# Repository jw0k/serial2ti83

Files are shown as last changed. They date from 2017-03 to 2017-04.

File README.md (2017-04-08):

# serial2ti83
A program for Arduino Uno that makes it possible to connect a TI-83 calculator to a computer

## Introduction
This program turns an Arduino Uno board into an adapter between a TI-83 graphing calculator and a computer. In order to use it upload `serial2ti83.ino` to an Arduino board using the standard Arduino IDE and connect the 2.5mm jack port on the bottom of TI-83 to Arduino according to the following table:

| Jack port | Arduino | 
|:---:|:---:|
| sleeve | GND pin |
| tip | pin 2 |
| ring | pin 3 | 
   
You can now run some linking program, e.g. **TiLP** and start exchanging data (upload programs, take screenshots, dump ROM, manage variables, etc.). In case of TiLP make sure to go to File->Change Device first and choose **GrayLink** cable and TI-83 calc.

_Optional_: before uploading `serial2ti83.ino` it is recommended to increase the size of hardware serial buffers to make the connection more reliable. Open `HardwareSerial.h` from you Arduino installation folder (usually `C:\Program Files (x86)\Arduino\hardware\arduino\avr\cores\arduino`) and change these 2 lines:

    #define SERIAL_TX_BUFFER_SIZE 64
    #define SERIAL_RX_BUFFER_SIZE 64

to:

    #define SERIAL_TX_BUFFER_SIZE 256
    #define SERIAL_RX_BUFFER_SIZE 256
    
## Schematic

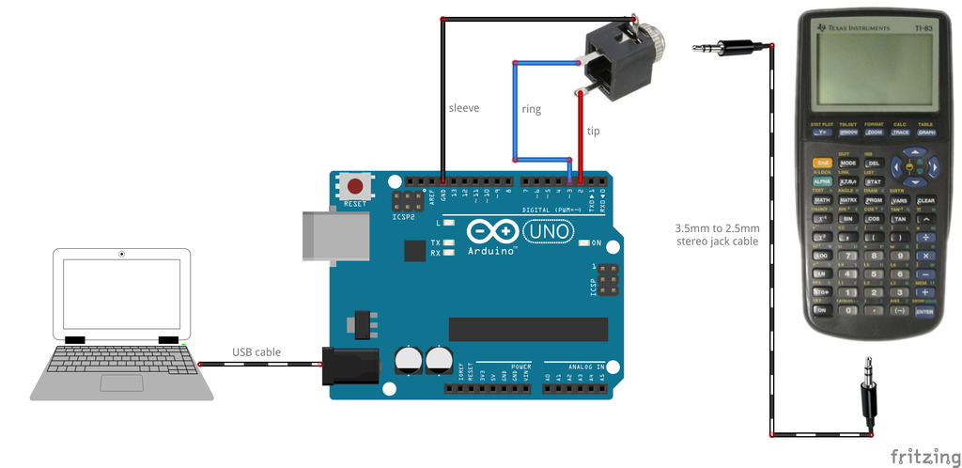
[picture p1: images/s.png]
schematic


## Putting it in a box
Here is an example of how you can put an Arduino board inside a box and attach a 3.5mm jack socket to the box to make a device that is convenient to use.

### List of required items
* Arduino Uno board (or clone)
* plastic project box (search for "ABS Plastic Electronic Enclosure Project Box Black 103x64x40mm" on **Banggood**, it's about $3.5)

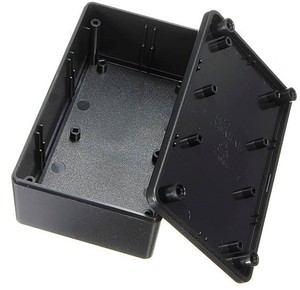
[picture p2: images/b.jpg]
box


* 3.5mm panel mounted stereo jack socket (eBay, $0.99)

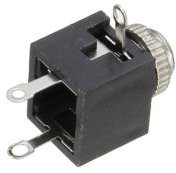
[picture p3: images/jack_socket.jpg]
jack socket


* nylon M3x10mm standoffs (eBay, $1.69 for 25 pieces)
* nylon M3x6mm philips screws (eBay, $1.79 for 25 pieces)
* 3.5mm to 2.5mm stereo jack cable (eBay, $0.99)

*Note: not every 2.5mm jack plug fits TI-83 smoothly. You may need to file away bits of plug's plastic housing so it goes all the way into the socket*

* some jumper cables
* basic tools (soldering iron, philips screwdriver, dremel tool, drill, files, etc.)

### Assembling the device

The first step is to attach standoffs to the Arduino board:

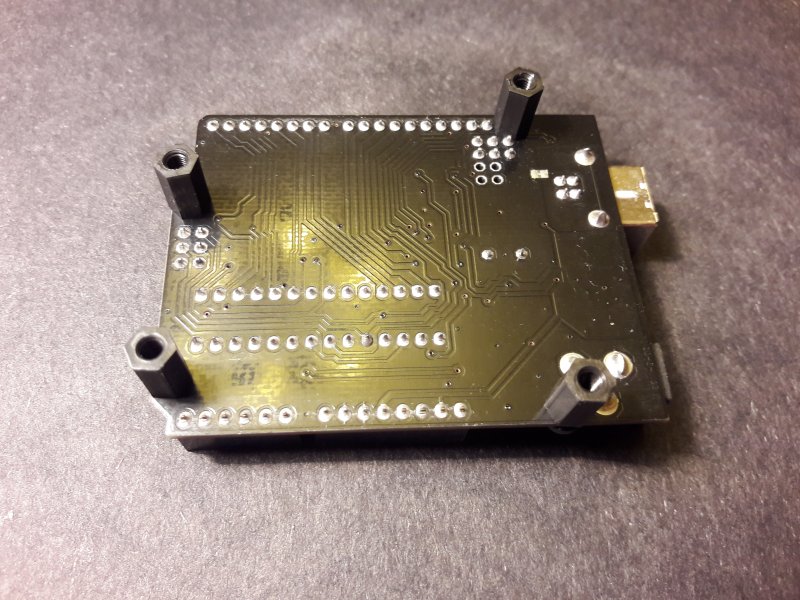
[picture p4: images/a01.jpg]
a01


Sometimes you will need to file edges of the DC socket and connector headers to make space for screws.

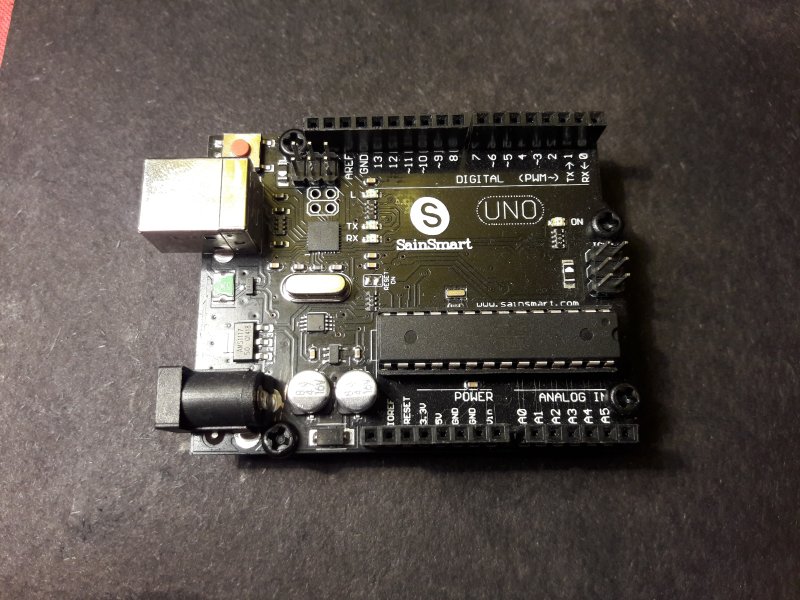
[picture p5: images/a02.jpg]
a02


Drill 4 holes in the bottom part of the box. The holes should match Arduino's layout:

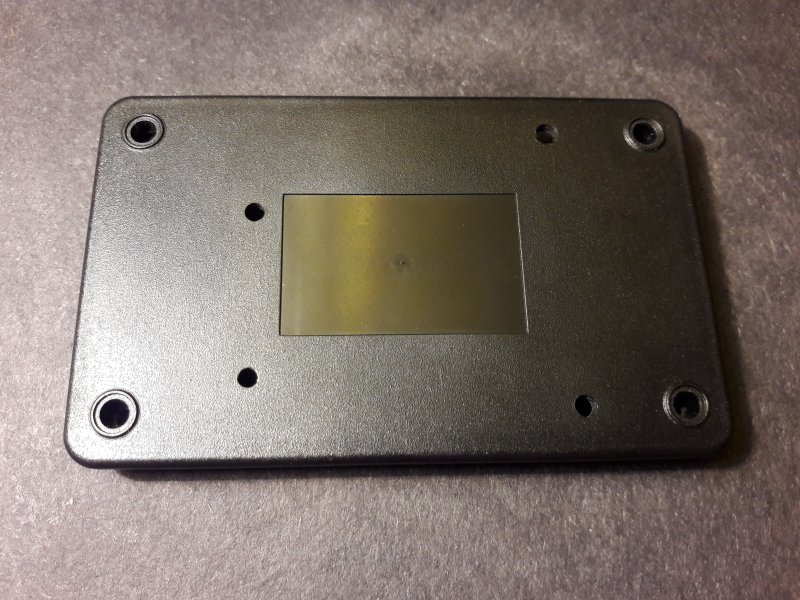
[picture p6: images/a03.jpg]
a03


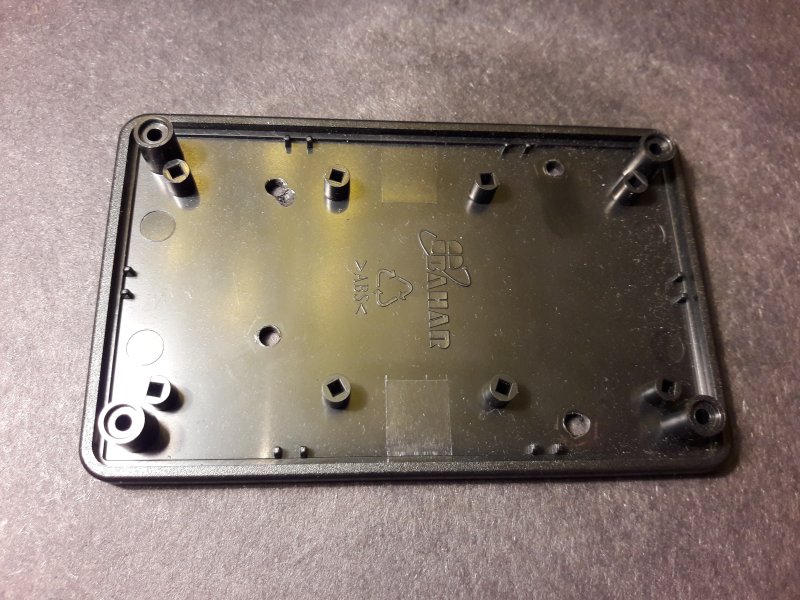
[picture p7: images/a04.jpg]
a04


Screw the Arduino board to it:

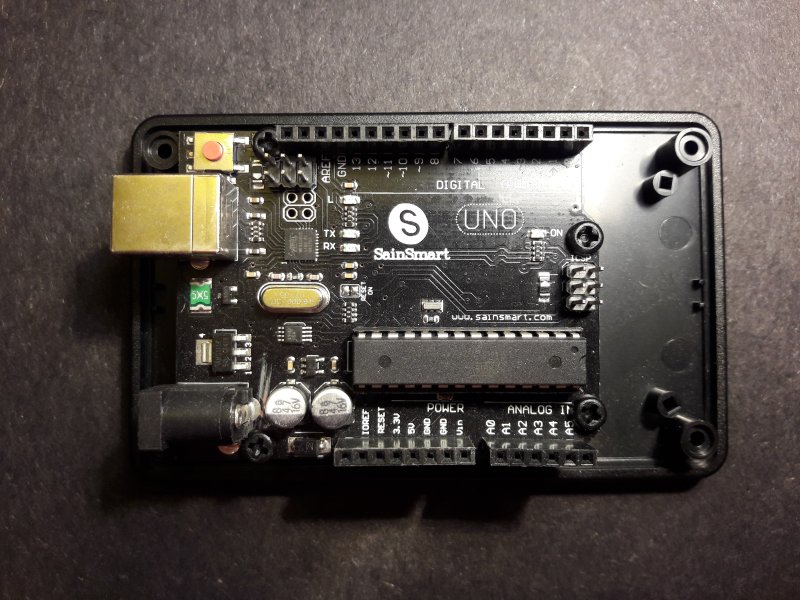
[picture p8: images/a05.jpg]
a05


Make a rectangular opening for the USB plug in the top part of the box. You may use a drill and finish with a file. The opening should be correctly positioned so that it matches with the USB socket.

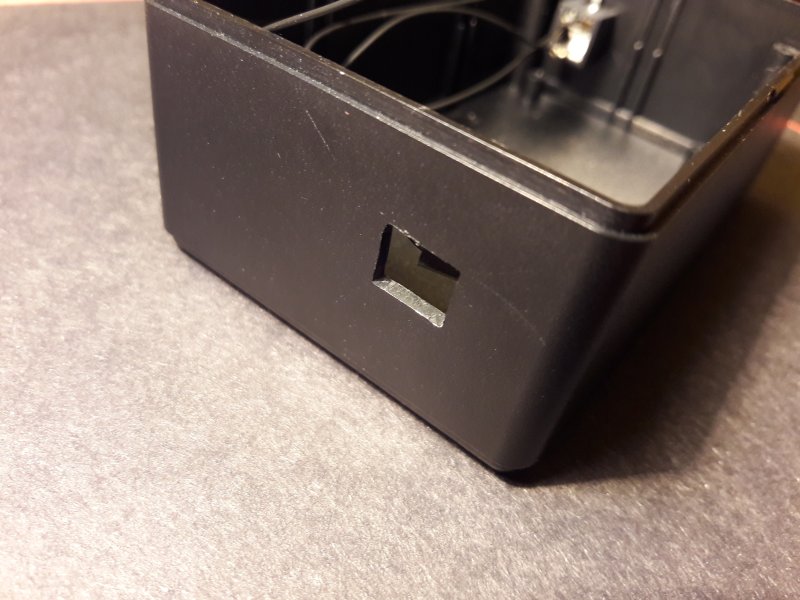
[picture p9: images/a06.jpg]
a06


Drill a hole on the other side of the top part of the box and attach the 3.5mm jack socket. Solder 3 jumper cables to it.

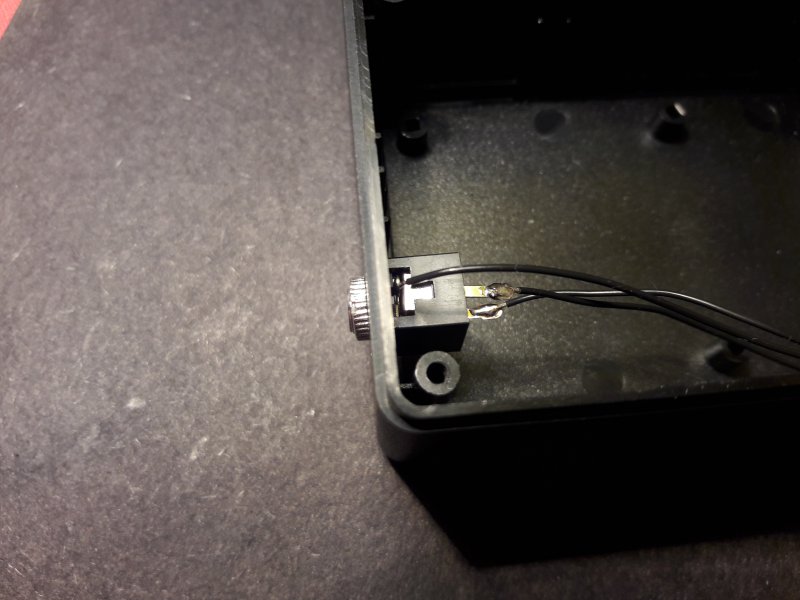
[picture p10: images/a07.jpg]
a07


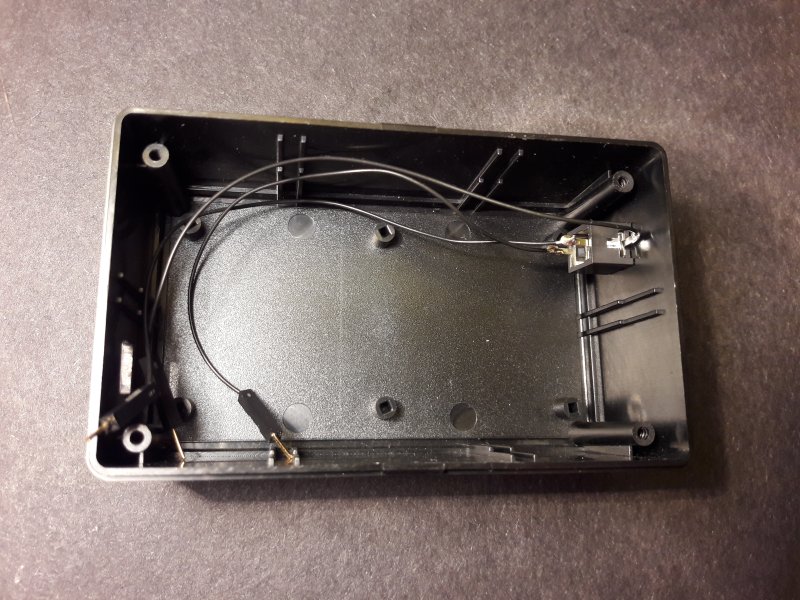
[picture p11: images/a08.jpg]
a08


Connect the jumper cables to the Arduino (see schematic above).

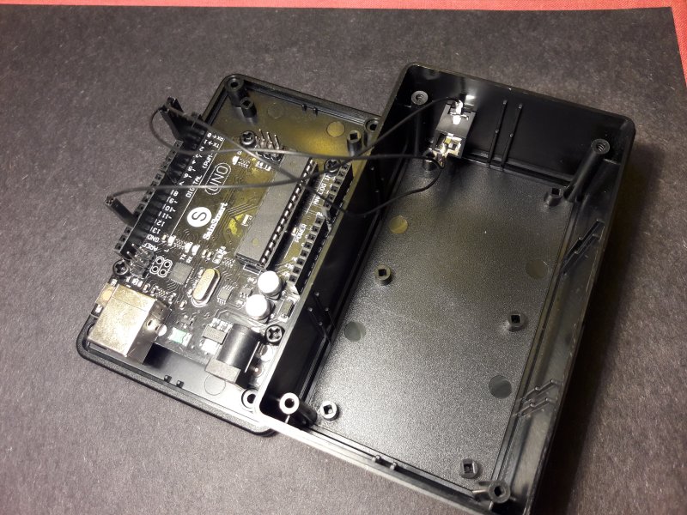
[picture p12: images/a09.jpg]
a09


Assemble the box. Use the 4 screws included with it.

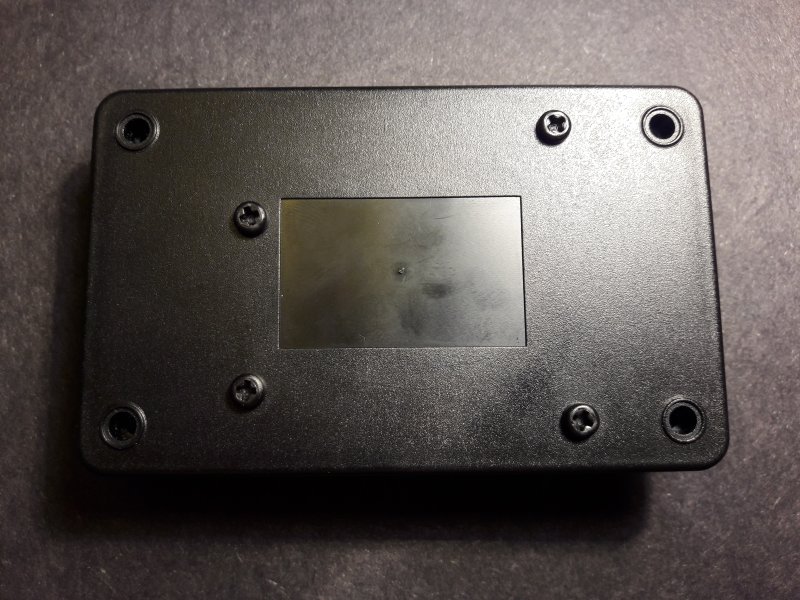
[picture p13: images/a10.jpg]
a10


Insall 4 rubber feet:

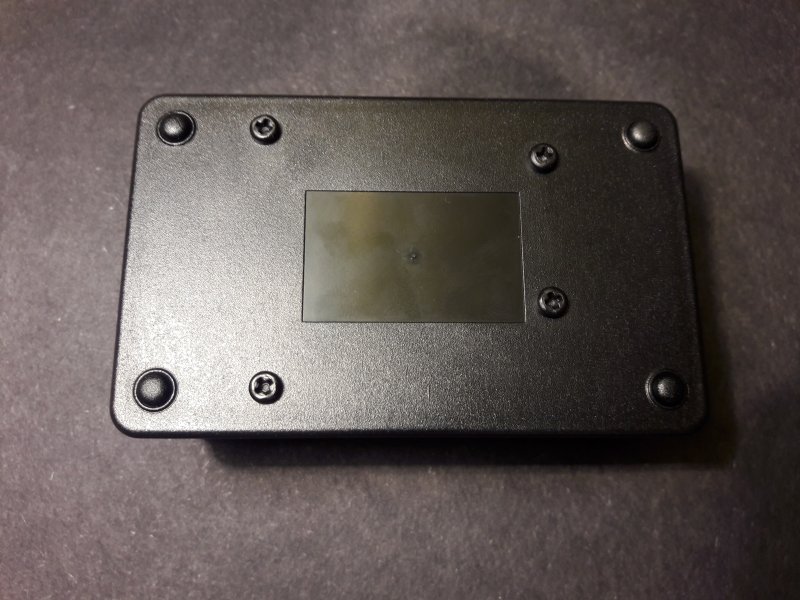
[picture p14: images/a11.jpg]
a11


This is the final result:

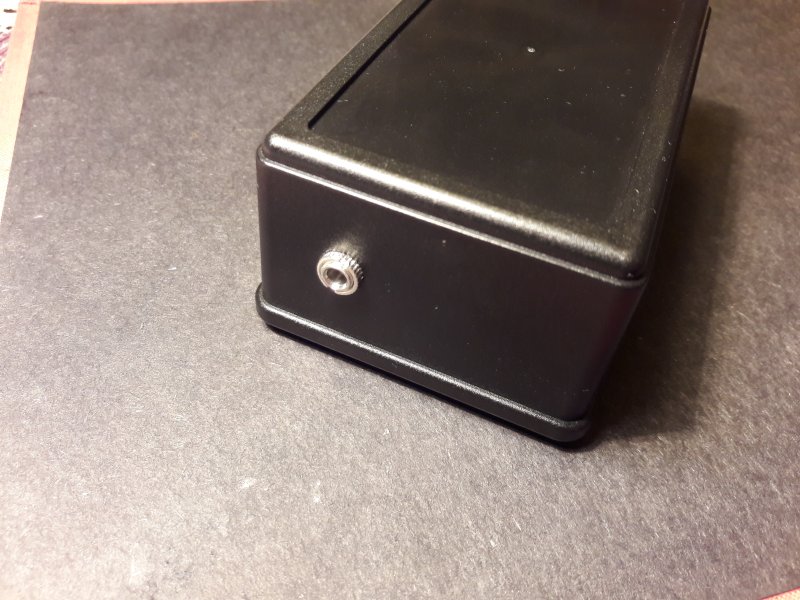
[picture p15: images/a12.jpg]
a12


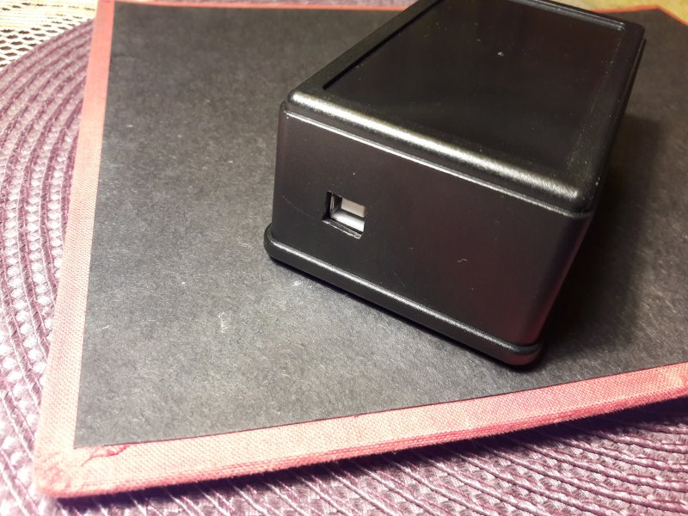
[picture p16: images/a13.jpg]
a13


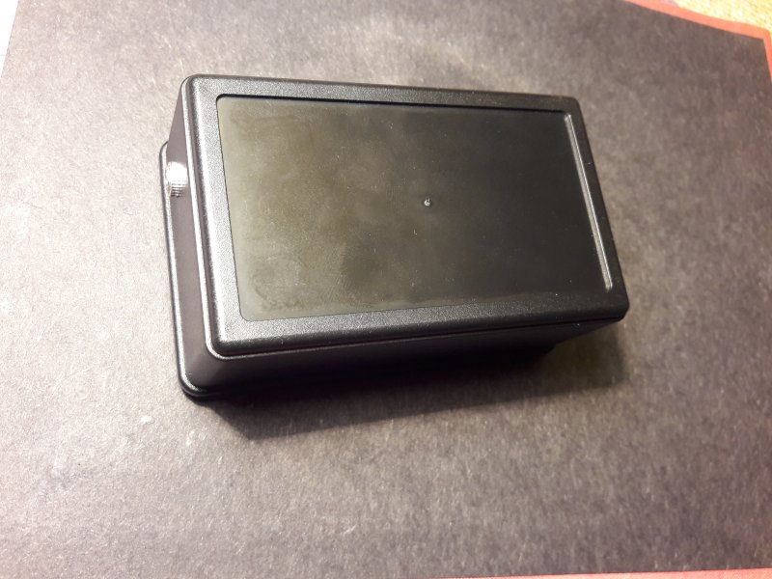
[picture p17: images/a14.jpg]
a14


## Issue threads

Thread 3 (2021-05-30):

is it possible to use with a nano

skylersell, 2021-05-30:
Hi I tried to use an arduino nano but it failed its a chinese nano

heltslut, 2021-11-26:
> Hi I tried to use an arduino nano but it failed its a chinese nano

I got it working with a chinese nano. Didn't change anything in serial2ti83.ino, just uploaded it.

My settings in Arduino IDE:
Tools > Board: Arduino Nano, Processor:  ATmega328P (Old bootloader), port: [select your port].

Connect TIP and RING to D2 and D3, and SLEEVE to GND on the arduino nano. Connect the 2,5mm jack to the TI-83+.

I then plugged in the nano to my windows 10 laptop, started the calculator > started TI Connect > TI DeviceInfo > Select TI Device recognized COM1, Gray Cable, TI-83 Plus.

I was then able to upload a new OS because i bricked the calc last year by accidentally interrupting a software transfer.

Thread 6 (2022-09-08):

I am getting an error with a TI-83+ and i can't resolve it.

meeper123, 2022-09-08:
the error is
"Msg: timeout occured while reading from the device.
Cause: check that link cable is plugged and/or the calculator is ready."
I can't seem to fix it
I have the port right, the cable set too "graylink" and I have the code unchanged(for the arduino Uno)
If anyone still uses this please help.

Stoutscientist, 2023-03-15:
Did you ever get this working? I'm having the same issue on my Arduino Uno.

meeper123, 2023-03-15:
> Did you ever get this working? I'm having the same issue on my Arduino Uno.

I did eventually get it to work reliably, I can't remember what I did, I'll install ti connect software, I'll update you once I get it working again.

Stoutscientist, 2023-03-15:
> > Did you ever get this working? I'm having the same issue on my Arduino Uno.
>
> I did eventually get it to work reliably, I can't remember what I did, I'll install ti connect software, I'll update you once I get it working again.

Thank you so much!

meeper123, 2023-04-27:
I am so sorry for the late reply, I got caught up in some things. Here are [all the files](https://drive.google.com/drive/folders/1VbgLqNRsPF2al2W2KnN13rwV-02KUW_q?usp=sharing)

- download TILP from sourceforge or the TILP website

- open the ino file in the folder named "USB Serial ti83" and then upload to Arduino uno
- close Arduino ide and open "device manager" (search it up after pushing windows key)
- find the com port of arduino uno (should be "arduino uno (ComXX)")
- right click on com port, select properties, port settings, Advanced, and set com port to COM1 COM2 COM3 or COM4 (make sure there is no in use next to it)
- open TILP, push CTRL+D
- set port to the same number of the com port
- set cable to gray link
- calc as your calculator, click the small magnifying glass, then push OK
- select DIRLIST from top and you should see the calculators files

I those are what worked for me, if it doesn't work for you tell me and ill see if I can help

meeper123, 2023-04-27:
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

I am so sorry for the late reply, I got caught up in some things. Here are [all the files](https://drive.google.com/drive/folders/1VbgLqNRsPF2al2W2KnN13rwV-02KUW_q?usp=sharing) make sure to download whole folder and not just the files

- download TILP from sourceforge or the TILP website

- open the ino file in the folder named "USB Serial ti83" and then upload to Arduino uno
- close Arduino ide and open "device manager" (search it up after pushing windows key)
- find the com port of arduino uno (should be "arduino uno (ComXX)")
- right click on com port, select properties, port settings, Advanced, and set com port to COM1 COM2 COM3 or COM4 (make sure there is no in use next to it)
- open TILP, push CTRL+D
- set port to the same number of the com port
- set cable to gray link
- calc as your calculator, click the small magnifying glass, then push OK
- select DIRLIST from top and you should see the calculators files

I those are what worked for me, if it doesn't work for you tell me and ill see if I can help

Stoutscientist, 2023-05-04:
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

Wow, it actually worked! Thank you so much! This INO file seems to be different from the main one, do you mind if I create my own repo with it?

meeper123, 2023-05-04:
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

Only thing I changed was the hardware serial library in the buffer size, with the library included with folder. If you do a repo make sure it is the whole folfer with the INO file and cpp/H files

MeneerJansen, 2023-06-26:
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

I tried but it just won't work for me. I connected my TI Voyage 200 to a Windows computer. The TI is on port COM3. If a TI calculator is not attached to the Arduino, then shouldn't TILP **at least** recognize the Arduino as a Gray Cable? Absolutely nothing is recognized when I click the icon of the magnifying glass...

Should I activate some sort of communications screen on the TI calculator?

meeper123, 2023-06-26:
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

On TILP what did you have the calculator set as, maybe try setting the calculator as ti-92 or ti-89 titanium [page 715~740](https://paginas.fe.up.pt/~ntiec/wp-content/uploads/2015/04/Manual-Voyage-200.pdf) You could try using [Ti Connect](https://education.ti.com/en/products/computer-software/ti-connect-sw). I'm not to certain on what would've caused it, It could be as simple as a poor connection in the i/o port. did the calculator freeze or become unresponsive to key presses when you plugged in the Arduino

what OS do you use and what settings do you have on TILP

MeneerJansen, 2023-06-27:
> what OS do you use and what settings do you have on TILP? Maybe try setting the calculator as ti-92 or ti-89 titanium [page 715~740](https://paginas.fe.up.pt/~ntiec/wp-content/uploads/2015/04/Manual-Voyage-200.pdf) You could try using [Ti Connect](https://education.ti.com/en/products/computer-software/ti-connect-sw). I'm not to certain on what would've caused it, It could be as simple as a poor connection in the i/o port. did the calculator freeze or become unresponsive to key presses when you plugged in the Arduino

The problem appeared to be **purely** with the jack plug. The 2.5 mm plug that TI uses on the Graph Link cables have no "indent" on the tip. All jack plugs that you can buy in electronic shops have an indent in the tip. An average basic jack plug just won't work. I tried to solder some lead on the tip and filed the excess off. And it worked, sort of. But it might damage the calculator. So now I use the black jack to jack connection cable that came with the second hand TI-85 that I bought with some fiddling (crocodile clips) and now it works.

So for everybody reading this: try get an official TI cable, if only for the jack connector.

SpeeterYT, 2023-11-16:
I also have this Problem, Ti Connect sometimes says it can see my Ti-89, but then crashes when I try to select it.
TiLP never shows it in the List but sometimes is able to load a screenshot (strange, I know), but If I try to transmit a file, it says "Msg: timeout occured while reading from the device. Cause: check that link cable is plugged and/or the calculator is ready.
System: (1977249328) The system cannot find the path specified." or just the timeout part without the "Cause".
I am using the code provided by @meeper123, with no succes. My arduino is a UNO clone and my cable is from a "DATA CONNECTION KIT" for the Ti8x (it says windows 3.xx is requiered on the back of the box...). I cut the Serial port of (which didn't work with a sketchy china serial to usb adapter) and soldered jumper cables to the leads.
This could be a coincidence but the last time the screenshot transfer worked, I pushed the cable in pretty hard to see if it was the Cable.
I also adjusted the Timeouts:
`const unsigned long TXTIMEOUT = 100; //ms
const unsigned long RXTIMEOUT = 50; //ms`
In TiLP the timeouts are at the defaults.
Does somebody know what to do?

MeneerJansen, 2023-11-17:
I have to correct my last post. A generic 2.5 mm TRS Jack plug does work for me. However, like many have stated - I should have listened - a TI calculator needs the jack to be pushed in deeper than usual.

I ordered some generic 2.5 mm jacks from Aliexpress and soldered the wires on it. The outside is from black plastic and the jack itself is from metal. I used a Dremel and one of those round sandpaper drums that comes with it (as a matter of fact it comes w/ a lot of spares of those drums). That sandpaper proved strong enough to sand some of the metal off the metal jack plug in such a way that it fits now. My "jack" problems are gone now!

It's hard to describe what I've done, hope you get what I mean. I've made photo's that might clarify... See attachments too this post.

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

@SpeeterYT : this may or may not solve your troubles. I got the same error messages. It's harder than one might think to properly connect to a TI calculator. God luck! :)

SpeeterYT, 2023-11-17:
> @SpeeterYT , have you tried using the ti-89's USB port to connect to a computer or are you trying the I/O port, if you are using the Arduino I believe you have to use the I/O port. do you have an image of the connector or a link from where you ordered it

Only the Ti-89 Titanium has usb, the normal one doesn't

SpeeterYT, 2023-11-17:
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

Okay, the only wierd thing is, that the cable I'm using is FOR a 89 and also sort of "locks" when pushed in.
But I could try something.
I've also thought of opening the calc and soldering wires onto the pads

SpeeterYT, 2023-11-17:
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

Now I just opened the calc and soldered wires onto it, whick worked!
The problem I'm having now is, that sstart doesn't seem to work (or any other program)

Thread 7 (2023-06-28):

Would it be possible to convert the code to act as a Silver Link cable?

MeneerJansen, 2023-06-28:
In Linux you can not use TILP with this Arduino. TLIP for Linux will only connect w/ a Gray Link via a real physical serial (DB9) port, not USB (i.e /dev/ttyACM0).

The so-called Silver Link cable is USB. So if the Arduino would "act" like a Silver Link cable that would be great! Would it be possible to alter the .ino code so that the Arduino Uno acts like a Silver Link instead of a Grey Link cable?

MeneerJansen, 2023-06-29:
Answer to own question: yes it's possible and people on Github already did this.

1. It looks like the author of _libticables2_ has to finally changed his code to use `/dev/ttyACM` instead of `/dev/ttyS` in Linux.  See: https://github.com/debrouxl/tilibs/ and https://github.com/debrouxl/tilibs/commit/01782c21da30fcddfbc9bdeb5ca15e12d112483a. However I couldn't compile his most recent source code at the time of writing (26 July 2023) and used a workaround (see point 3 furtheron).

2. I followed the changed Github _serial2ti83_ `ReadMe` ([link](https://github.com/jw0k/serial2ti83/blob/c28f195026e8d680e1c6031d7c63a6efb8fc5742/README.md)) to compile a newer version of `libticables2.so` and copied that to the directory in which my Linux computer (Ubuntu 20.04) installed it, i.e.:  `/usr/lib/x86_64-linux-gnu/`. I deleted the old library (`libticables2.so.7.0.0`) and renamed the newly compiled `libticables2.so.8.0.0` to the old name `libticables2.so.7.0.0` (= very, very, very dirty hack!).

Tip: there's a tiny typo there. Where it says "As of July 31, 2018, that corresponds to lines **314** through 346." it should be line **341** instead of 314.

Without altering the Arduino .ino sketch - and thus without "updating" the Arduino as recommended in the changed Readme - the program TILP that I installed via my package manager in Linux now works (that is: with the Dupont cables connected to digital pins 2 an 3 instead of the recommended analog pins 0 and 1).

3. A word about the source code of `libticables`. The most recent source code on the official Github page of `tilibs` (which contains the library to connect your PC to a TI calculator via the TI cable: libticable2) would not compile on my computer. So I downloaded the version from 2018 that the authors of the changed Readme used too: [link](https://github.com/debrouxl/tilibs/tree/1a7d1321be761f447ab60c399934e737f180792a). That works.

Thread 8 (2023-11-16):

Problems with Ti-89

SpeeterYT, 2023-11-16:
I also have a problem:
Ti Connect sometimes says it can see my Ti-89, but then crashes when I try to select it.
TiLP never shows it in the List but sometimes is able to load a screenshot (strange, I know), but If I try to transmit a file, it says "Msg: timeout occured while reading from the device. Cause: check that link cable is plugged and/or the calculator is ready.
System: (1977249328) The system cannot find the path specified." or just the timeout part without the "Cause".
I am using the code provided by @meeper123, with no succes. My arduino is a UNO clone and my cable is from a "DATA CONNECTION KIT" for the Ti8x (it says windows 3.xx is requiered on the back of the box...). I cut the Serial port of (which didn't work with a sketchy china serial to usb adapter) and soldered jumper cables to the leads.
This could be a coincidence but the last time the screenshot transfer worked, I pushed the cable in pretty hard to see if it was the Cable.
I also adjusted the Timeouts:
const unsigned long TXTIMEOUT = 100; //ms const unsigned long RXTIMEOUT = 50; //ms
In TiLP the timeouts are at the defaults.
Does somebody know what to do?

meeper123, 2023-11-17:
I would look for any shorts to ground, maybe try using TILP instead of ti-connect and check if there is a difference. it could just be a loose or dirty connector. I don't have a ti-89 to test it on so I can't see if it is a problem with code, do you have the cable type set as gray link.

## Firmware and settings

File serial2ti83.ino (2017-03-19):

const int TIP = 2; //arduino port where the tip of the stereo jack plug is connected
const int RING = 3; //arduino port where the middle part of the stereo jack plug is connected
const unsigned long TXTIMEOUT = 50; //ms
const unsigned long RXTIMEOUT = 5; //ms

void sendByte(uint8_t byte)
{
    unsigned long currentTime;

    for (int i = 0; i < 8; ++i)
    {
        bool bit = byte & 0x01;
        byte >>= 1;

        //poll both lines until they are both high, which means we're ready to send a bit
        currentTime = millis();
        while (digitalRead(TIP) == LOW || digitalRead(RING) == LOW)
        {
            if (millis() - currentTime > TXTIMEOUT)
            {
                return;
            }
        }

        int ourLine;
        int oppositeLine;
        if (bit)
        {
            ourLine = RING;
            oppositeLine = TIP;
        }
        else
        {
            ourLine = TIP;
            oppositeLine = RING;
        }

        //send a bit by pulling appropriate line low
        pinMode(ourLine, OUTPUT);
        digitalWrite(ourLine, LOW);

        //wait for opposite line to become low
        currentTime = millis();
        while (digitalRead(oppositeLine) == HIGH)
        {
            if (millis() - currentTime > TXTIMEOUT)
            {
                pinMode(ourLine, INPUT_PULLUP);
                return;
            }
        }

        //release our line
        pinMode(ourLine, INPUT_PULLUP);

        //wait for opposite line to become high
        currentTime = millis();
        while (digitalRead(oppositeLine) == LOW)
        {
            if (millis() - currentTime > TXTIMEOUT)
            {
                return;
            }
        }
    }
}

bool getByte(uint8_t& byte)
{
    unsigned long currentTime;
    uint8_t result = 0;

    for (int i = 0; i < 8; ++i)
    {
        //poll both lines until one of them becomes low
        currentTime = millis();
        while (digitalRead(TIP) == HIGH && digitalRead(RING) == HIGH)
        {
            if (millis() - currentTime > RXTIMEOUT)
            {
                return false;
            }
        }

        int ourLine;
        int oppositeLine;
        bool bit = (digitalRead(RING) == LOW);
        result >>= 1;
        if (bit)
        {
            ourLine = TIP;
            oppositeLine = RING;
            result |= 0x80; //bits are always transmitted LSb first (least significant bit)
        }
        else
        {
            ourLine = RING;
            oppositeLine = TIP;
        }

        //acknowledge a bit by pulling appropriate line low
        pinMode(ourLine, OUTPUT);
        digitalWrite(ourLine, LOW);

        //wait for opposite line to become high
        currentTime = millis();
        while (digitalRead(oppositeLine) == LOW)
        {
            if (millis() - currentTime > RXTIMEOUT)
            {
                pinMode(ourLine, INPUT_PULLUP);
                return false;
            }
        }

        //release our line
        pinMode(ourLine, INPUT_PULLUP);
    }

    byte = result;
    return true;
}

void setup()
{
    //turn off the built-in LED
    pinMode(LED_BUILTIN, OUTPUT);
    digitalWrite(LED_BUILTIN, LOW);

    Serial.begin(9600);

    //configure both lines to be in a high-impedance state and enable pull-up resistors
    pinMode(TIP, INPUT_PULLUP);
    pinMode(RING, INPUT_PULLUP);
}

void loop()
{
    //forward incoming data from PC to the calculator
    while (Serial.available() > 0)
    {
        sendByte(Serial.read());
    }

    //forward incoming data from calculator to the PC
    uint8_t byteFromCalc;
    if (getByte(byteFromCalc))
    {
        Serial.write(byteFromCalc);
    }
}

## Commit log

2017-04-08 add schematic
2017-04-08 add new schematic
